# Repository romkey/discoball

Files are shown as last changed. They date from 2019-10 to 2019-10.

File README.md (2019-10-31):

# discoball ESP32 FastLED Board

*Use this hardware at your own risk. I am not responsible if it does not work for you, if you waste money on it, if it catches fire and burns down your home, if your hair falls out or if it causes an election to go sour. I promise no support; you are on your own.*

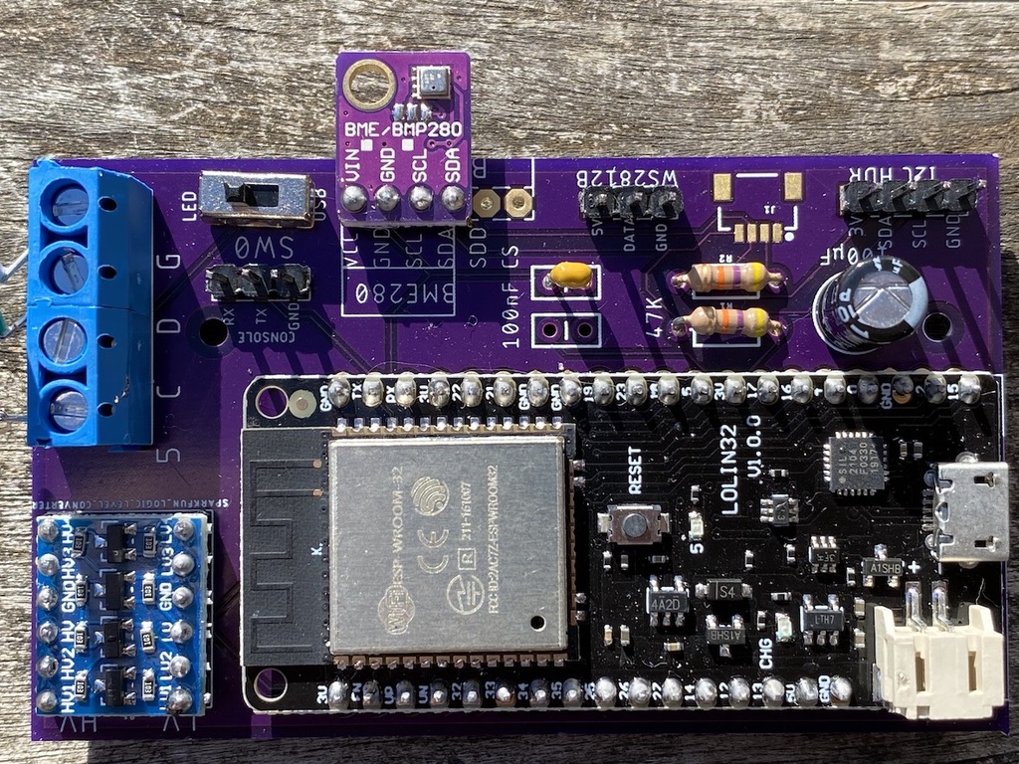
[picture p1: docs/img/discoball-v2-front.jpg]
Discoball
 

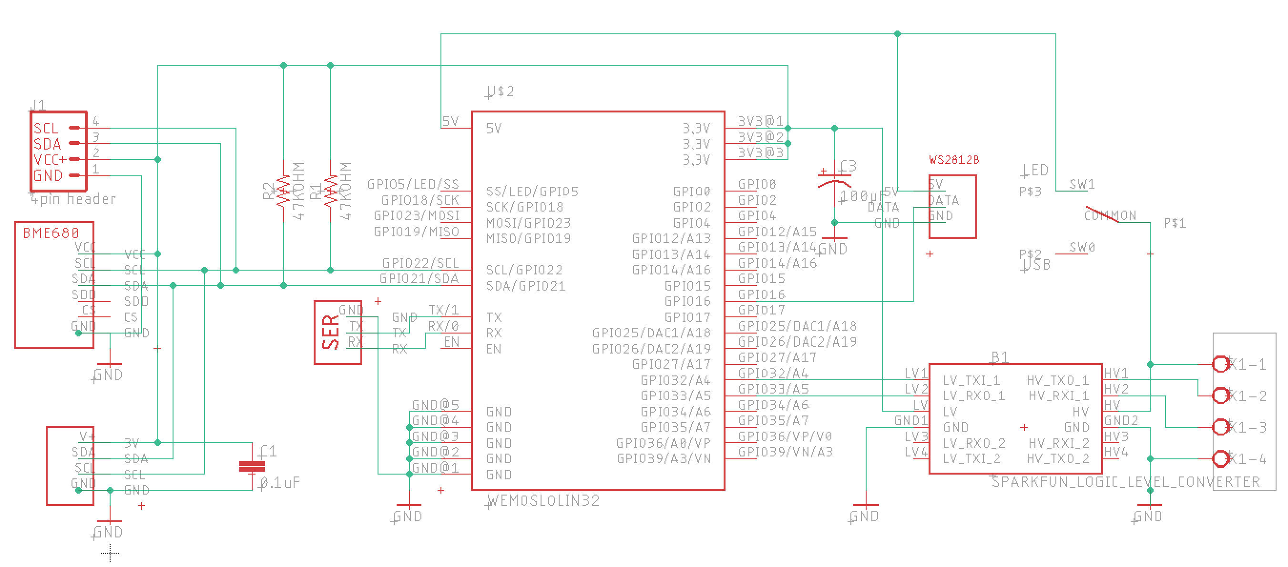
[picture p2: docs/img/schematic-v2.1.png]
schematic


Discoball is a simple printed circuit board intended to run [vendo](https://github.com/romkey/vendo) FastLED-based software with a variety of types of RGB LEDs with built-in controllers, like the WS2812B or APA102. These LEDs usually need to be driven at 5V, so the board includes hardware to level shift the ESP32's 3.3v signals to 5V.

The discoball also includes an optional [BME280](https://www.bosch-sensortec.com/bst/products/all_products/bme280) or [BME680](https://www.bosch-sensortec.com/bst/products/all_products/bme680) air temperature/humidity/pressure and (on the 680) VOC sensor, and optional connections for external I2C devices.

Discoball is Open Source Hardware. This repo includes [schematic](eagle/discoball-v2.sch) and [board](eagle/discoball-v2.brd) files for Autodesk Eagle.

You can [order Disocball boards from OSHPark](https://oshpark.com/shared_projects/Rrn2Y8C1).

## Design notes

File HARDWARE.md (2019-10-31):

# Discoball Hardware Guide v2

## Parts List

| Part | Use | Qty|notes|
|----|----|---|----|
|ESP32 Lolin32 breakout board| CPU/wifi | 1|
|Sparkfun level shifter breakout board|voltage converter|1|
|4 pin screw terminal|LED connection|1|
|SPST or SPDT switch|power selection|1|3mm/breadboard compatible|
|100µF electrolytic capacitor|bypass capacitor|1|
|BME280/BME680|optional air sensor|1|_optional_|
|47K ohm resistors|I2C pullups|2|_optional_|
|100nF capacitor|bypass capacitor|1|_optional_|

Many of the parts are optional. The only mandatory parts are:

### LOLIN32 ESP32 breakout board

The LOLIN32 has a LIPO battery charger on it and has 16 pins on one side and 20 on the other. *Beware that some devices that are labelled "LOLIN32" have a different pinout and won't work on the Discoball board.*

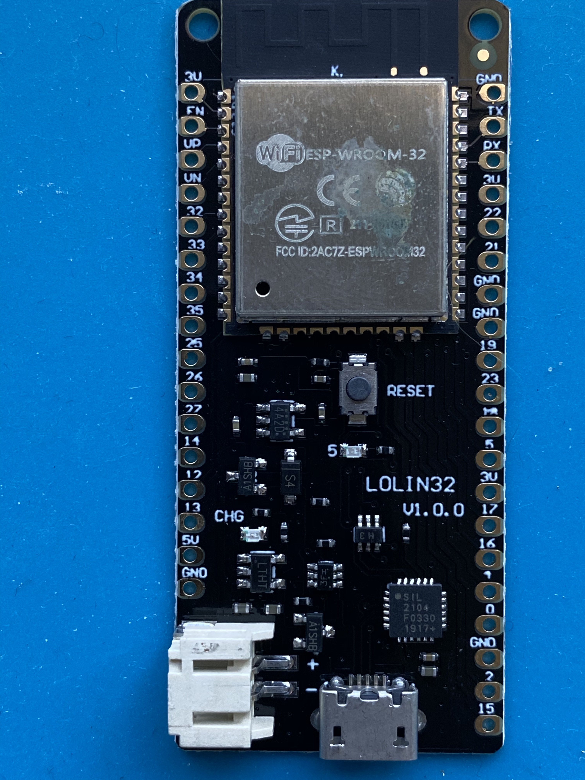
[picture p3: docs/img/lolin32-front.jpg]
LOLIN32 front
 
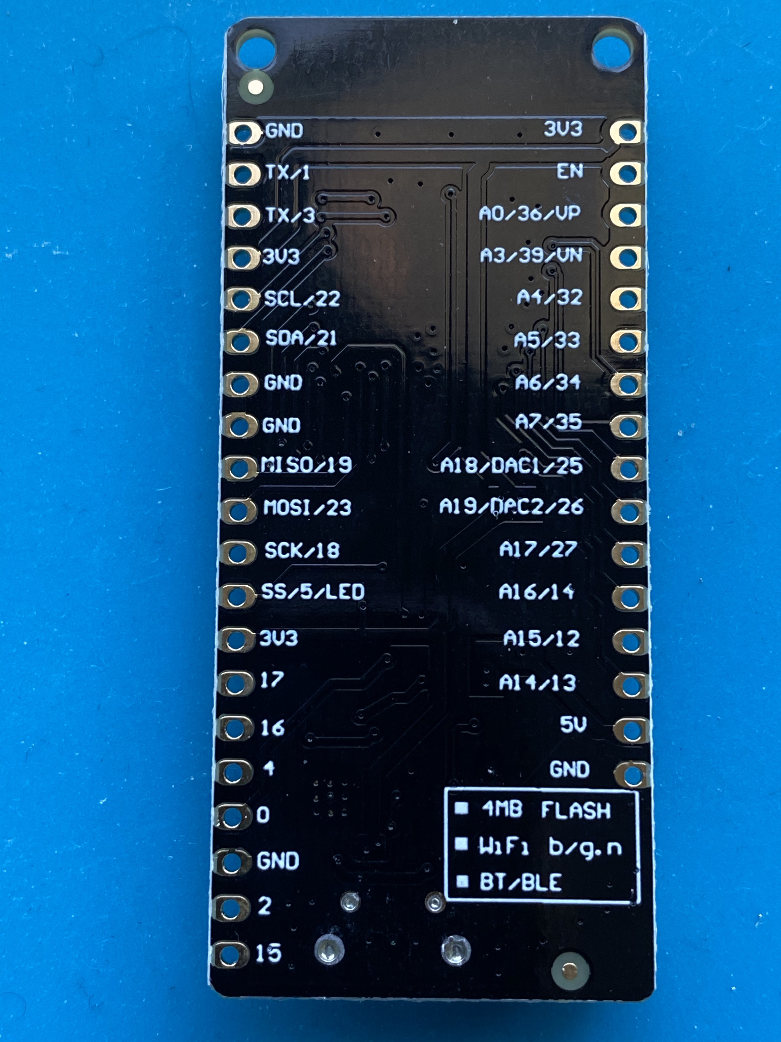
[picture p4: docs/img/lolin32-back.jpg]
LOLIN32 back
 

Some board listings on Amazon and AliExpress use the label "LOLIN32" but have a different pinout, so please be careful. Also beware that the "LOLIN D32" is not the same as the "LOLIN32".

I've also purchased these LOLIN32 boards from AliExpress and had them work well.

### Level shifter

You'll want SparkFun's level shifter board or another that's pin-compatible. The high voltage (HV) side of the breakout board wants to be by the edge of the PCB; the low voltage (LV) wants to be the side nearest the ESP32.

[SparkFun Logic Level Converter - Bi-directional](https://www.sparkfun.com/products/12009)

Level shifter front 

### 4 pin screw terminal

You can skip this if you really want to, but you'll need a way to attach your LED wires to the board. If you solder them directly be sure to provide some kind of strain relief (like hot glue or something else so that the wires don't break or pull out of the board).

### SPST or SPDT switch

The switch lets you choose to power the board from the LEDs' 5V feed or the 5V  feed from the ESP32's USB port. The board has three holes so that you can use a SPST or SPDT switch. Only a SPST is required.

I used these switches from Amazon: 

https://www.amazon.com/gp/product/B007QAJUUS

If you'd like to mount a switch on a case you could use any SPST or SPDT switch, solder a header on the PCB and wire the switch to the header.

## Optional Parts

If you want to use a BME280 or BME680 breakout board or an external I2C device you'll need to solder on the 47K ohm resistors and the 100nF capacitor. The board has an error with positions for two 100nF capacitors - you only need one and can solder it in either position.

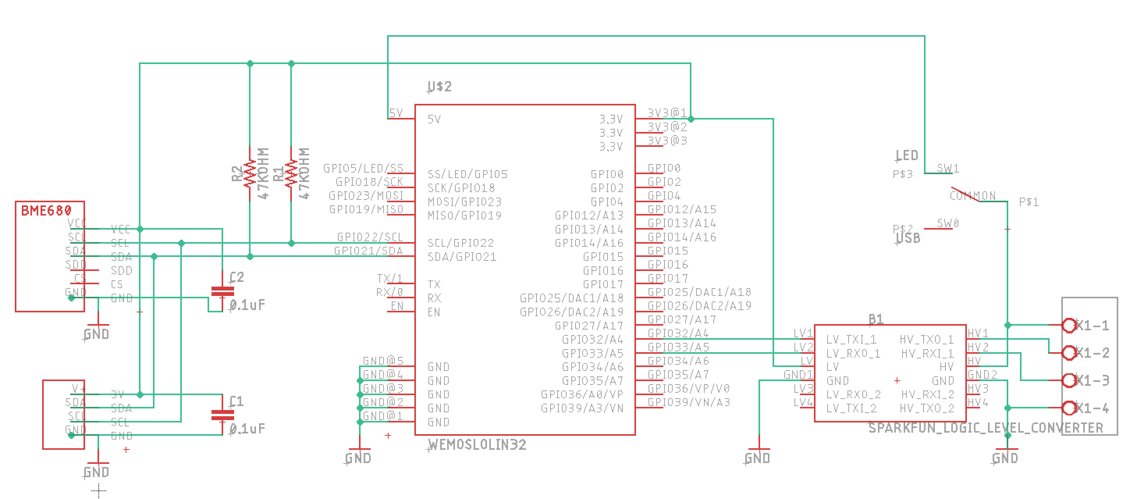
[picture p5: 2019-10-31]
docs/img/schematic-v1.png

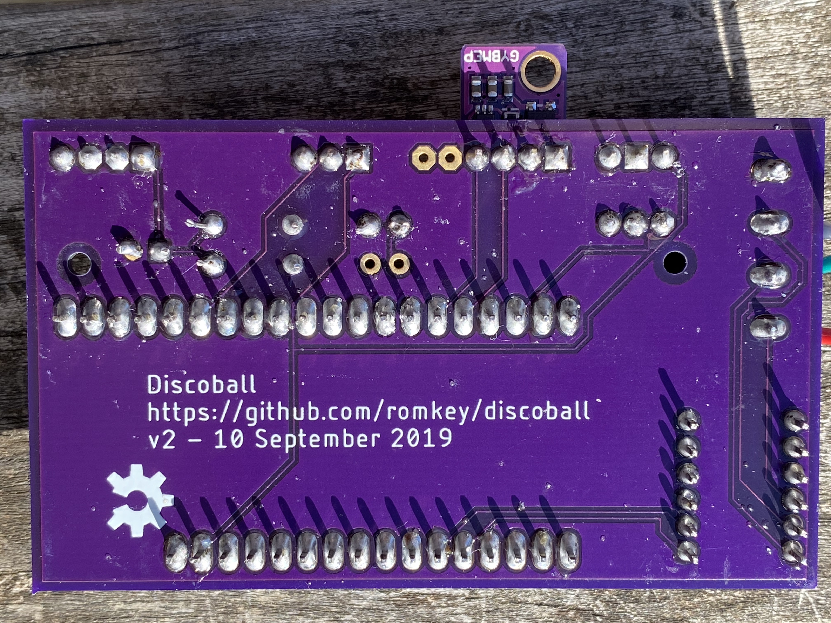
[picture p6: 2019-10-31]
docs/img/discoball-v2-back.jpg

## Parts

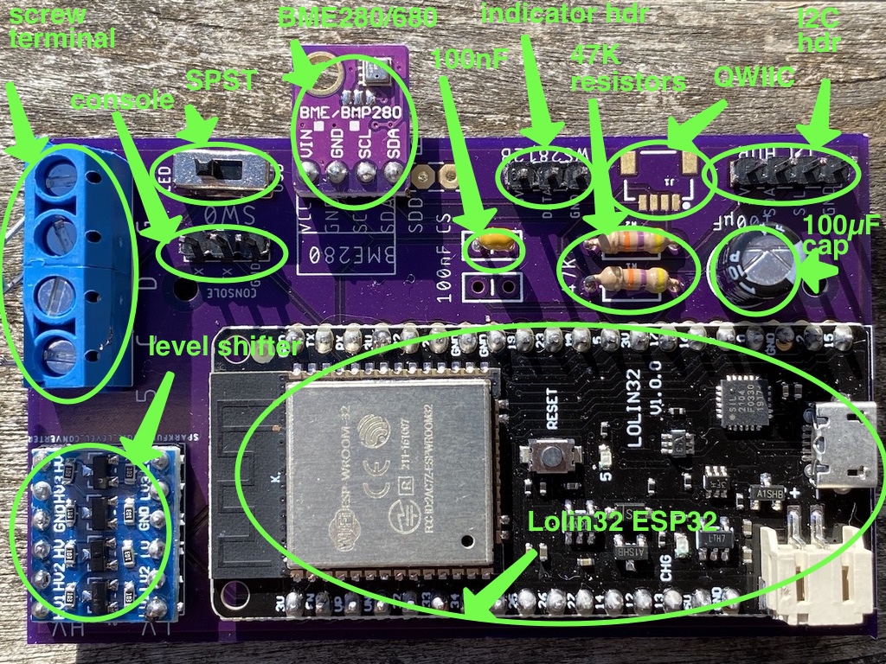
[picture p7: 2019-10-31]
docs/img/discoball-v2-parts.jpg

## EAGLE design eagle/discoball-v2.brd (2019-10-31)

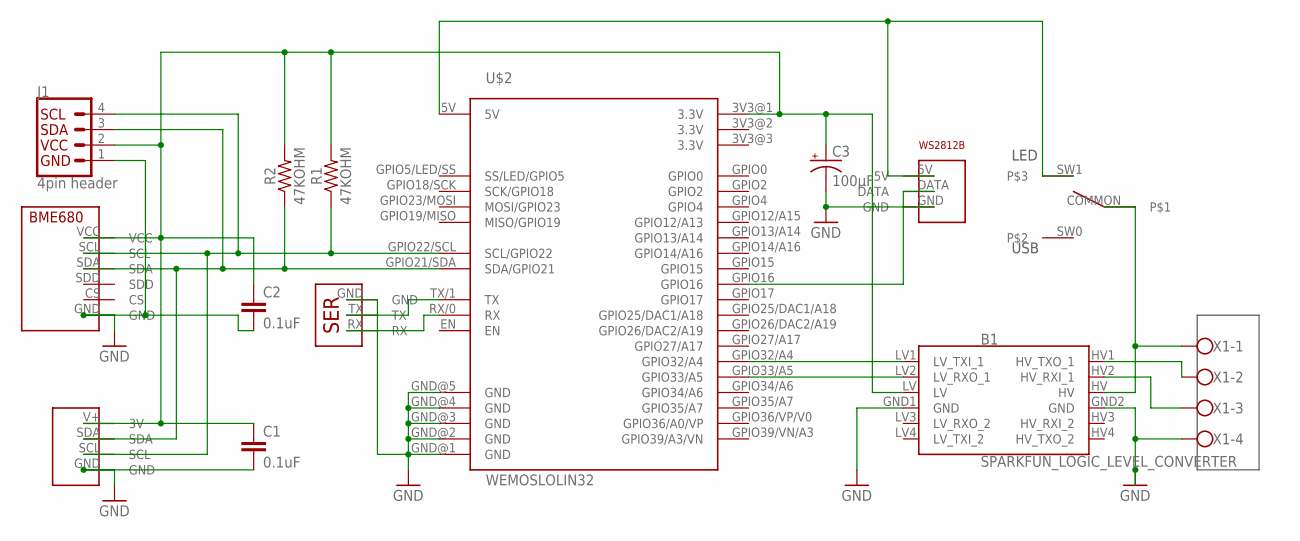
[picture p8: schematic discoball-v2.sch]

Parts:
B1: SPARKFUN_LOGIC_LEVEL_CONVERTER
C1, C2: 0.1uF; CAP-PTH-SMALL-KIT
C3: 100µF; CPOL-RADIAL-100UF-25V
J1: 4pin header; 1X04_1MM_RA
R1, R2: 47KOHM; AXIAL-0.3-KIT
U$1: BME680BREAKOUT
U$2: WEMOSLOLIN32; LOLIN32VAR1
U$3: I2CHEADER
U$4: SPDTSWITCH
U$6: SERIALHEADER
U$7: WS2812BHEADER
X1: W237-4

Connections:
3.3V: B1.LV, C1.1, C2.1, C3.1 (+), J1.2 (VCC), R1.P$2 (2), R2.P$2 (2), U$1.VCC, U$2.3V3@1 (3.3V), U$2.3V3@3 (3.3V), U$3.V+ (3V)
5V: U$2.5V, U$4.SW1, U$7.5V
GND: B1.GND1 (GND), B1.GND2 (GND), C1.2, C2.2, C3.2 (-), J1.1 (GND), U$1.GND, U$2.GND@1 (GND), U$2.GND@2 (GND), U$2.GND@3 (GND), U$2.GND@4 (GND), U$2.GND@5 (GND), U$3.GND, U$6.GND, U$7.GND, X1.4
unnamed: J1.4 (SCL), R1.P$1 (1), U$1.SCL, U$2.GPIO22/SCL (SCL/GPIO22), U$3.SCL
unnamed: J1.3 (SDA), R2.P$1 (1), U$1.SDA, U$2.GPIO21/SDA (SDA/GPIO21), U$3.SDA
unnamed: B1.HV2 (HV_RXI_1), X1.3
unnamed: U$2.RX/0 (RX), U$6.RX
unnamed: B1.LV1 (LV_TXI_1), U$2.GPIO32/A4
unnamed: B1.LV2 (LV_RXO_1), U$2.GPIO33/A5
unnamed: U$2.TX/1 (TX), U$6.TX
unnamed: B1.HV1 (HV_TXO_1), X1.2
unnamed: B1.HV, U$4.COMMON, X1.1
unnamed: U$2.GPIO16, U$7.DATA

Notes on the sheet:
LED
USB

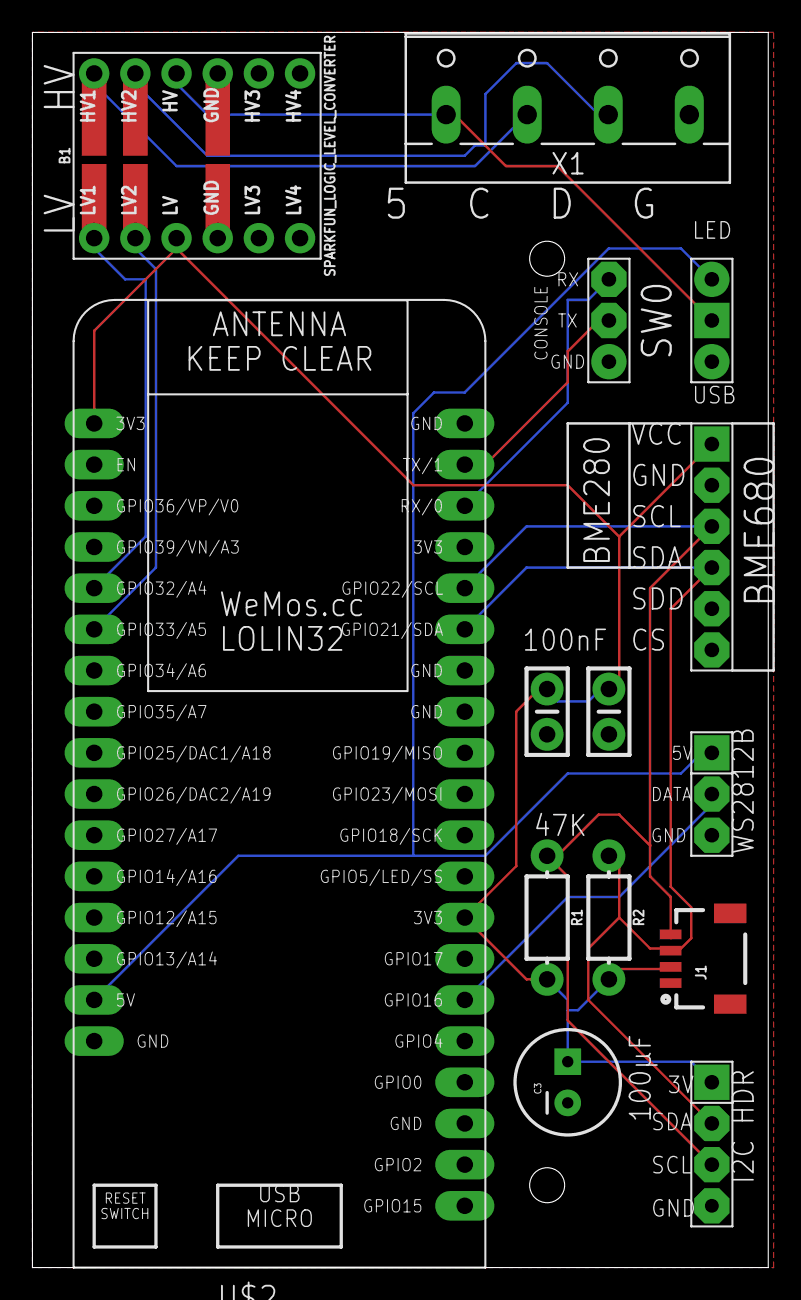
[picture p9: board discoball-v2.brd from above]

Board: 2 copper layers, 45.4 x 76.2 mm, 15 parts (1 on the bottom side), 13 nets.

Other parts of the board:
U$5: OSHW-LOGO-L

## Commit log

2019-10-31 get some documentation in there
    [discoball-v1.brd, discoball-v2.brd, discoball-v2.sch]
2019-10-31 schematic is .png
2019-10-31 I2C support

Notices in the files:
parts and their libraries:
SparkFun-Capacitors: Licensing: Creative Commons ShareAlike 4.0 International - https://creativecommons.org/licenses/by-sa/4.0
